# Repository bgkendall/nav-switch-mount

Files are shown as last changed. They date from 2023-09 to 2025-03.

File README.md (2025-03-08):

# Nav. Switch Mount

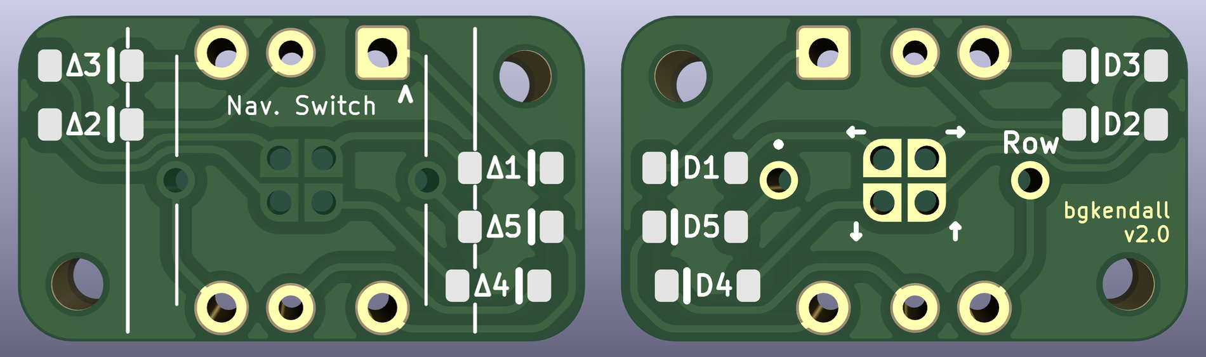
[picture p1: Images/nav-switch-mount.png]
5-way Navigation Switch Mount


This is a simple PCB for mounting through-hole 5-way navigation switches such as
the [ALPS SKQUCAA010]. It is intended for use in keyboard projects and provides
a way to both secure a nav. switch and easily wire it into a keyboard matrix.

This switch has been discontinued by ALPS, but equivalents can be obtained from
[Adafruit][ada-504] and various vendors on [AliExpress][ali-SKQ][^1].

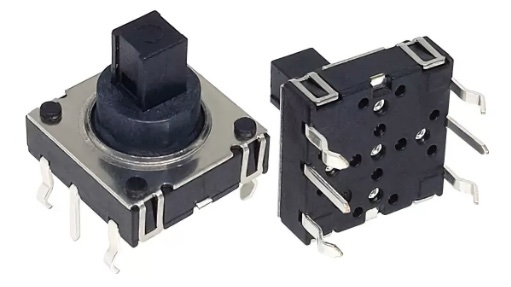
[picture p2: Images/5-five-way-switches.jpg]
5-way Navigation Switches


This repository contains the [KiCad] PCB design files and [Gerber format] files
for PCB production. Zipped Gerber packages are included in the release assets.

[^1]: If no results are shown, try refreshing the page.

## Additional Components Required

 * 1 × [ALPS SKQUCAA010] (or equivalent) navigation switch
 * 5 × 1N4841 [SOD-123] SMD diodes

 ## Options

The current (v2) PCB is 22.9×13.2mm. The diodes can be mounted on either side of
the PCB. Connections to the board are via wires that align with MX switch centre
and alignment pins.

The first version of the PCB came in two variants:

 * **1-sided** — 24.3×13mm — the switch and diodes are all mounted on the top
    of the PCB.
 * **2-sided** — 22.3×12.6mm — the diodes are mounted on the opposite side of
    the PCB to the switch. Wire connections are via pads.

## Wiring

The switch and diodes are installed as marked. Diodes may be soldered on the
opposite side to the switch (positions D1—D5) or on the same side as the switch
(∆1—∆5) depending on preference. The PCB is wired into the [keyboard matrix] via
the holes on the underside. The *Row* hole/pad is the common pin for the switch
and should be connected to a row pin on the MCU. The other holes/pads should be
connected to columns, with the silkscreen near the connection point indicating
the direction (see notes below). The holes are specifically designed to line-up
with the centre and two alignment pins of an MX switch, allowing the wires to
easily run through to the back of the keyboard’s PCB. However, the best routing
will depend on the exact board being modified — in some cases it may be
desirable to run the wires between the plate and PCB.

It is recommended that masking tape is used to prevent solder from building up
on the upper side of the board (in a similar manner to when socketing an MCU)
and the wires will need to be soldered from the bottom side (i.e., from the
opposite direction from how a wire would normally be soldered).

### Notes

 * The markings on the silkscreen orient the diodes for **Column-to-Row** use.
   For a Row-to-Column matrix the diodes must be installed in the opposite
   direction.
 * The arrows point in the direction that the switch is actually pushed. This
   means that when viewed from the bottom the left and right arrows indicate
   right and left movement respectively.
 * The ‘•’ marking indicates the centre press action[^2].

[^2]: On the nav. switches I have used I have found the centre press to be both
      vague and twitchy and have left it unassigned on most layers.

## Mounting

### M2 Hardware

These PCBs are designed to be secured using M2 hardware. Two ~2.1mm holes will
need to be drilled through the keyboard’s plate (or, potentially, the keyboard’s
PCB, although this would need to be planned with great care!).

The mount points are in the same position relative to the centre of the PCB for
both variants.

### MX Adaptor

Alternatively, these PCBs can be used in conjunction with Kevin Eckert’s [Nav
Switch to MX Adapter][nav2mx]. The switch’s legs should be long enough to reach
past the bottom of the adaptor and through the mounting PCB. The switch’s legs
may need to be straightened for ease of soldering (be careful if doing this —
the fragility of these legs was one of the main prompts to create this board!).

For keyboards with a PCB, the adaptor can **only** be used top-mounted diodes
and the mounting board must be thinner than the usual 1.6mm to allow room for
the switch legs to be soldered[^3]. The legs will need to be trimmed back as
much as possible to avoid pressing on the keyboard PCB. There is not enough room
between a plate and a keyboard PCB for the adaptor and bottom-mounted diodes.

Careful consideration should be given to the order of assembly when using the
adaptor.

[^3]: At the time of writing 0.8mm PCBs seem to be available for no additional
      charge.

## Keycaps

Options for keycaps on navigation switches:

 * [Adafruit Black Rubber Joystick Nubbin Cap][ada-4697]
 * Kevin Eckert’s SA profile keycap for navigation switches is available
   alongside their [Nav Switch to MX Adapter][nav2mx] for mounting nav. switches
   in MX plates.
 * I have created three adaptors for attaching MX keycaps to navigation
   switches. The STL and glTF files, and more information can be found in the
   [*Adaptors* directory][adaptors]:
    * Nav Switch to MX Stem Adaptor (PCB mount) — this is for nav.
      switches that are mounted on the keyboard PCB.
    * Nav Switch to MX Stem Adaptor (plate mount)] — this is for
      nav. switches that are mounted using the Nav Switch to MX Adapter
      mentioned above.
    * Nav Switch to MX Keycap Adaptor (destructive) — this is perhaps the best
      option, *but* requires partially destroying a keycap!

[ALPS SKQUCAA010]: https://tech.alpsalpine.com/e/products/detail/SKQUCAA010/
[KiCad]: https://www.kicad.org
[Gerber format]: https://en.wikipedia.org/wiki/Gerber_format
[ada-504]: https://www.adafruit.com/product/504
[ada-4697]: https://www.adafruit.com/product/4697
[ali-SKQ]: https://www.aliexpress.com/w/wholesale-SKQUCAA010.html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
[SOD-123]: https://en.wikipedia.org/wiki/Small_Outline_Diode
[keyboard matrix]: https://www.pcbheaven.com/wikipages/How_Key_Matrices_Works/
[nav2mx]: https://www.thingiverse.com/thing:3958026
[adaptors]: https://github.com/bgkendall/nav-switch-mount/tree/main/Adaptors

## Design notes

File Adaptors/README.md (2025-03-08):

# Nav. Switch to MX Keycap Adaptors

## Nav Switch to MX Stem Adaptor (PCB mount)

This is for [nav. switches][ALPS SKQUCAA010] that are mounted on the keyboard PCB. The
top of the adaptor’s MX stem should line up with the stem tops of the MX switches. The
length of the adaptor combined with the inherent wobbliness of 5-way switches may make
this combination feel a little unstable.

The original model can be found on [Tinkercad][mx2navPCB]

## Nav Switch to MX Stem Adaptor (plate mount)

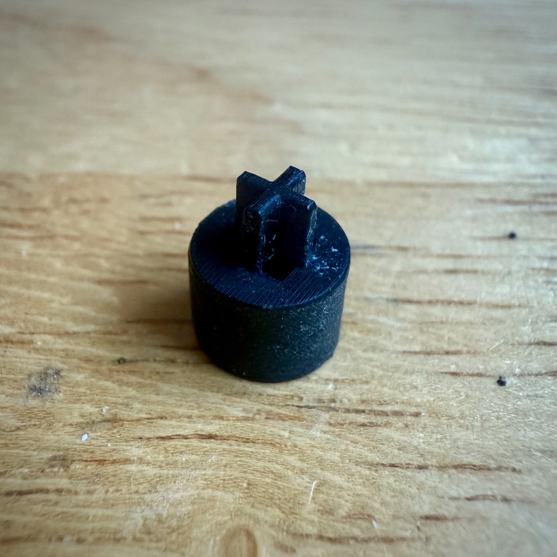
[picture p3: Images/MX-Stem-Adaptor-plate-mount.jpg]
Nav Switch to MX Stem Adaptor (plate mount)


This is for nav. switches that are mounted using switches mounted level with the plate
(e.g., using a [Nav Switch to MX Adapter][nav2mx]). However, the adapted keycaps will
be higher than those of surrounding MX switches, and because of the thin connection
between the nav. switch sleeve and the MX cross stem, this can be a little fragile.

The original model can be found on [Tinkercad][mx2navPlate]

## Nav Switch to MX Keycap Adaptor (destructive)

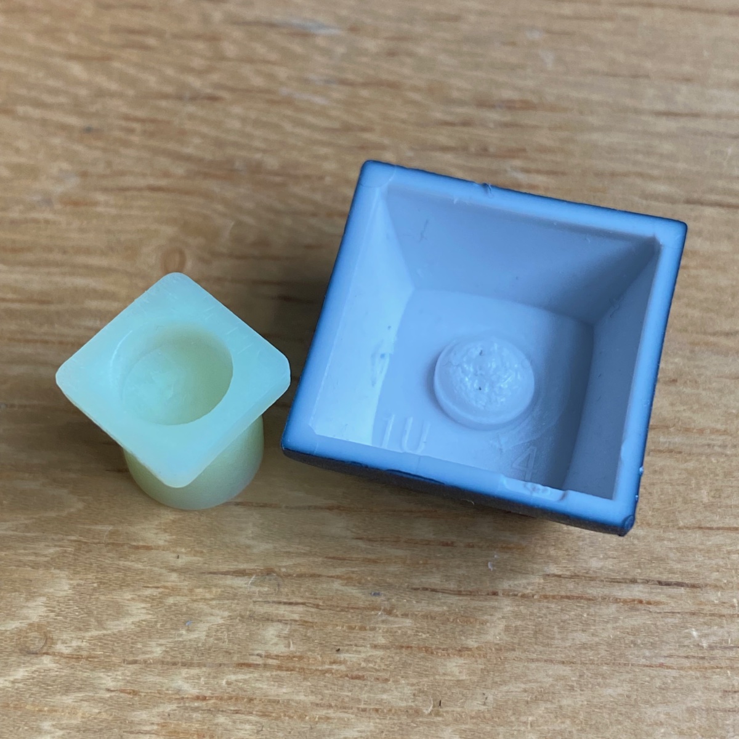
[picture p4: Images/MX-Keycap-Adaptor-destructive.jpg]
Nav Switch to MX Stem Adaptor (plate mount)


This design requires removing the stem[^1] of the keycap and glueing the adaptor in place.
This is the shortest adapter available, and, depending on the mounting setup, can allow
the adapted keycap to be level with others.

I used a Dremel to grind the keycap stem to a nub — it doesn’t need to be completely flat
as the adaptor has space, and a nub provides more contact area for the glue.

The original model can be found on [Tinkercad][mx2navDest]

[^1]: **I.e., irreversibly damaging the keycap!**

[ALPS SKQUCAA010]: https://tech.alpsalpine.com/e/products/detail/SKQUCAA010/
[nav2mx]: https://www.thingiverse.com/thing:3958026
[adaptors]: https://github.com/bgkendall/nav-switch-mount/tree/main/Adaptors
[mx2navPCB]: https://www.tinkercad.com/things/bekaGf7odDx-nav-switch-to-mx-stem-adaptor-pcb-mount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
[mx2navPlate]: https://www.tinkercad.com/things/7jTtJ6HvAXj-nav-switch-to-mx-stem-adaptor-plate-mount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
[mx2navDest]: https://www.tinkercad.com/things/3gL4wvWRLj1-nav-switch-to-mx-keycap-adaptor-destructive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

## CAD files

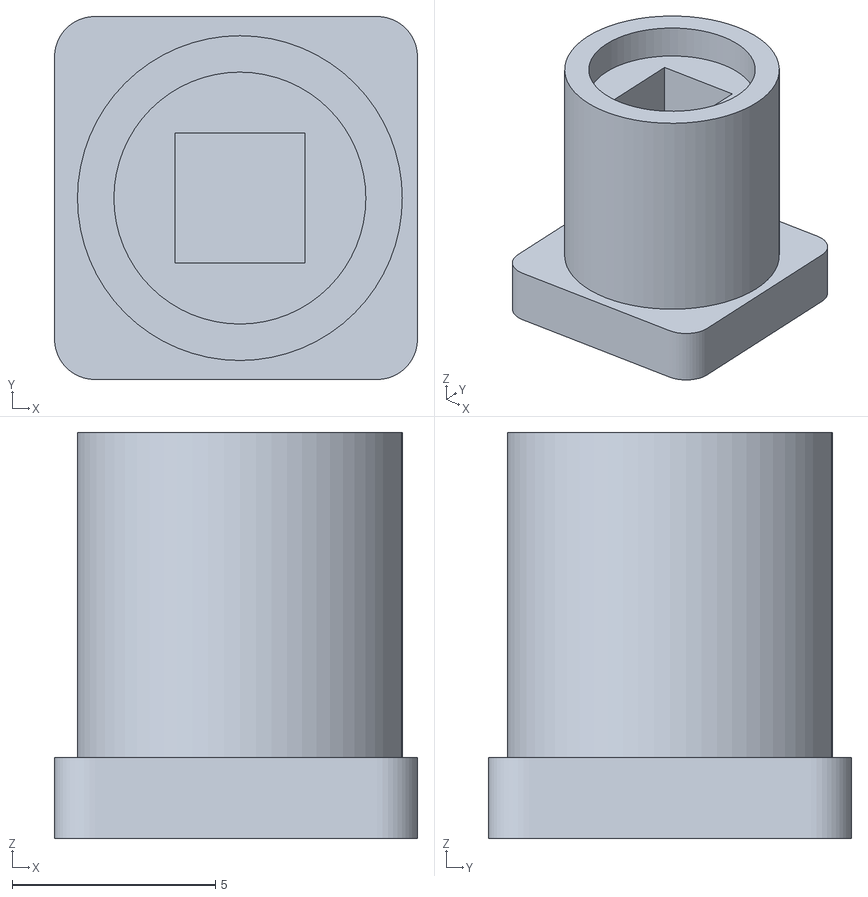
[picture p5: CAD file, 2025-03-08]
Adaptors/Nav Switch to MX Keycap Adaptor (destructive).stl
8.94 x 8.94 x 10.0

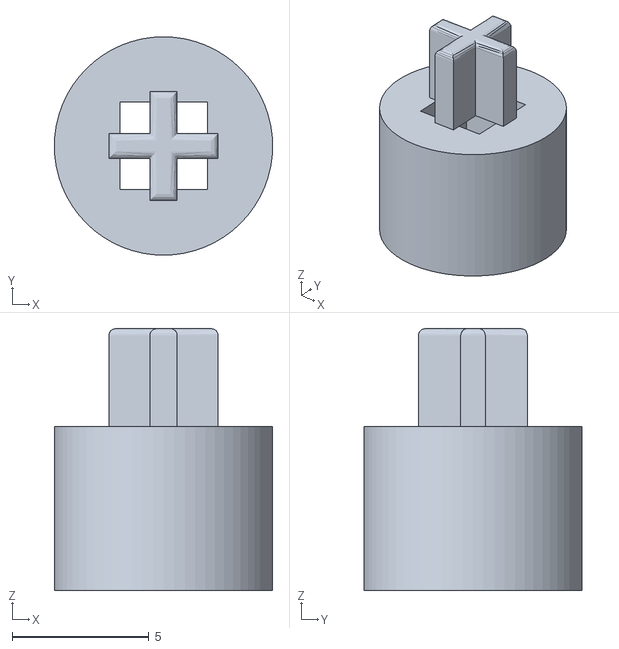
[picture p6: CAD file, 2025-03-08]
Adaptors/Nav Switch to MX Stem Adaptor (plate mount).stl
8.00 x 8.00 x 9.60

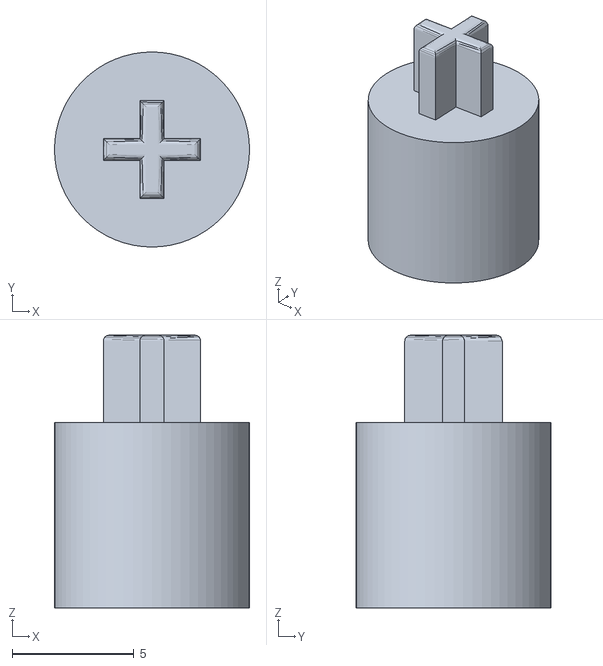
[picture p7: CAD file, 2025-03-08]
Adaptors/Nav Switch to MX Stem Adaptor (PCB mount).stl
8.00 x 8.00 x 11.2

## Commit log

2023-09-17 Initial check-in of Nav. Switch Mount PCB files
    [Nav Switch Mount.kicad_pcb, Nav Switch Mount.kicad_sch]
2023-09-17 Scoot D4 and D5 to the left to be same distance from switch as D1–3
    [Nav Switch Mount.kicad_pcb]
2023-09-17 Add rough layout schematic SVG
2023-09-17 Move footprints to project library
    Also:
    * Redesigned diode footprint with more compact labelling.
    * Redesigned switch footprint to centre on middle of switch and added 3D model.
    * Removed 3D model from header footprint.
    * Narrowed and widened PCB.
    [Nav Switch Mount.kicad_pcb, Nav Switch Mount.kicad_sch]
2023-09-18 Add Gerber files
    [Nav Switch Mount-B_Cu.gbl, Nav Switch Mount-B_Mask.gbs, Nav Switch Mount-B_Paste.gbp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]
2023-10-30 Rename “Nav Switch Mount” to “Nav Switch Mount (2-sided)”
    [Nav Switch Mount-B_Cu.gbl, Nav Switch Mount-B_Mask.gbs, Nav Switch Mount-B_Paste.gbp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]
2023-10-30 Add “Nav Switch Mount (1-sided)” as copy of 2-sided mount
    [Nav Switch Mount-B_Cu.gbl, Nav Switch Mount-B_Mask.gbs, Nav Switch Mount-B_Paste.gbp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]
2023-10-30 Updates after producing PCB
    * Increased pad around nav. switch pins
    * Decreased size of matrix connection pads
    [Nav Switch Mount.kicad_pcb]
2023-10-31 First version of 1-sided variant
    [Nav Switch Mount.kicad_pcb]
2024-05-03 Create version 2
    Main changes from v1:
    * Through-holes used instead of pads for wire connections
    * Wire connections align with MX switch holes
    * Diodes can be placed on either side
    * Diode pads are slightly larger
    [Nav Switch Mount.kicad_pcb, Nav Switch Mount.kicad_sch]
2024-05-03 Update folder structure
    * Nav Switch Mount (1-sided) → v1/1-sided
    * Nav Switch Mount (2-sided) → v1/2-sided
    * Nav Switch Mount (v2) → v2
    [Nav Switch Mount-B_Cu.gbl, Nav Switch Mount-B_Mask.gbs, Nav Switch Mount-B_Paste.gbp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]
2024-05-03 Update README and PCB image
2024-05-03 Remove order number
    Cost is no different for a board this small!
    [Nav Switch Mount.kicad_pcb]
2024-05-03 Add production files
    [Nav Switch Mount-B_Cu.gbl, Nav Switch Mount-B_Mask.gbs, Nav Switch Mount-B_Paste.gbp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]
2025-03-08 Add print files and additional information for keycap adaptors
    [Nav Switch to MX Keycap Adaptor (destructive).stl, Nav Switch to MX Stem Adaptor (PCB mount).stl, Nav Switch to MX Stem Adaptor (plate mount).stl]
2025-12-12 Update KiCad version
